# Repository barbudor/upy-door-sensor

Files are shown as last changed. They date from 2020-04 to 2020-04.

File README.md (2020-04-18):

# upy-door-sensor
Dead simple MQTT door-sensor based on ESP8266 (ESP01) with MicroPython

Using `umqttsimple.py` from [MicroPython-Lib](https://github.com/micropython/micropython-lib)
package (author: Paul Sokolovsky, license: MIT License).<br>
A big thanks to MicroPython authors and contributors.

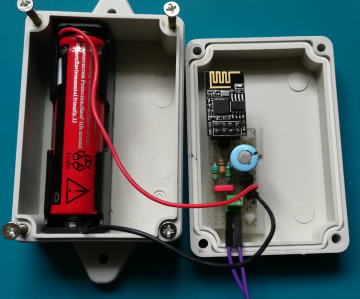
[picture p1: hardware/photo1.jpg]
photo should display here


# Principle of operation
The ESP8266 is maintained in permanent Deep Sleep state (do not connect GPIO16 to RESET).
A pulse is generated on RESET whenever the door opens and the switch closes, resulting in
waking up the ESP. Once awaken, the ESP8266 connects to the Wifi, the MQTT server and then
publish on a given topic before entering in Deep Sleep.

See hardware details in [`hardware/`](https://github.com/barbudor/upy-door-sensor/tree/master/hardware)
folder. Schematics avaible for both:
- [Circuit-Diagram.org](https://www.circuit-diagram.org/editor/)
- [Fritzing](http://fritzing.org/)

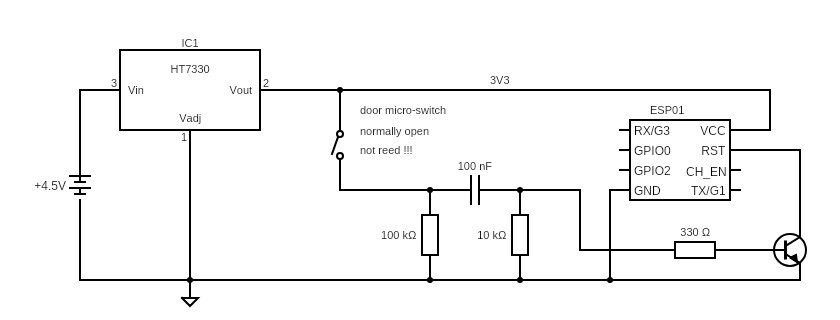
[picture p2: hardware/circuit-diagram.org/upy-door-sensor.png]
schematics should display here schematics

You must use a micro-switch which is open when the door is closed and closed when the door is open.
A reed switch is not suitable.

The MQTT message include a status for the door (always "open" as the sensor cannot detect
closing the door) and the VCC voltage. As soon as it drops below the regulator voltage, it means
that the battery is low and should be changed/charged.

# Configuration
No fancy web-server!
Configuration is performed by renaming `secrets_sample.py` as `secrets.py` and entering your
parameters. Should be self-explanatory.

Build and enjoy !

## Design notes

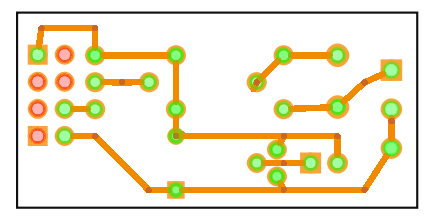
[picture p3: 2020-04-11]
hardware/fritzing/upy-door-sensor_pcb.png

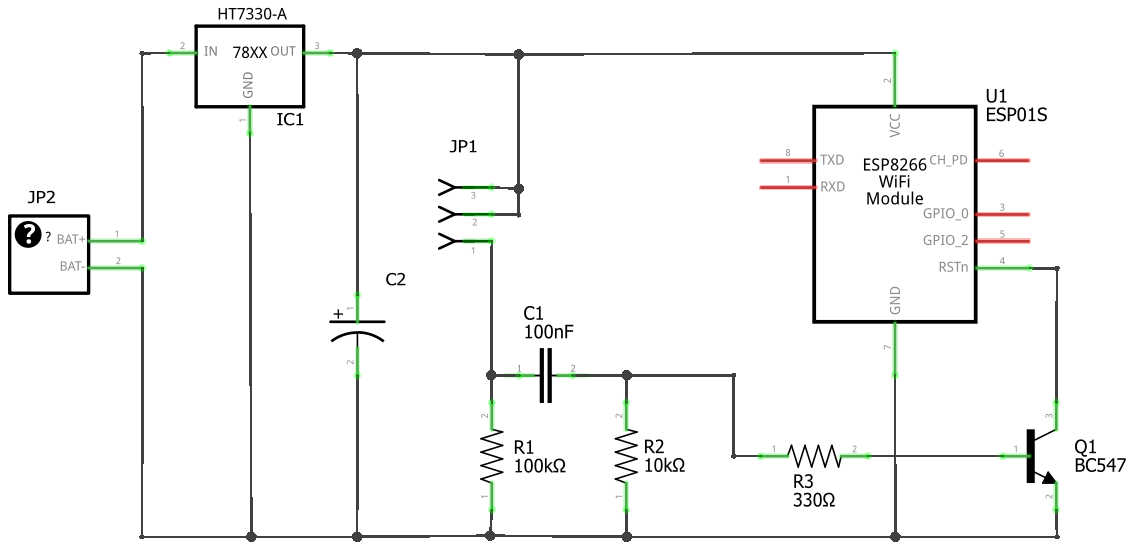
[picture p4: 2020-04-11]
hardware/fritzing/upy-door-sensor_schematics.png

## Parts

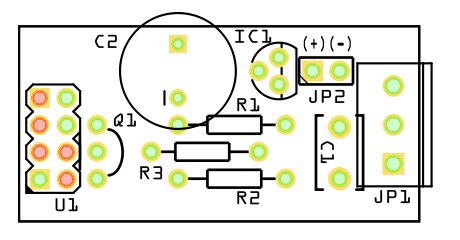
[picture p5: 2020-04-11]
hardware/fritzing/upy-door-sensor_parts-top.png

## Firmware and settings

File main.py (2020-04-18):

"""
    Quick and dirty MQTT door sensor
"""

import time
import network
import ubinascii
import machine
from umqttsimple import MQTTClient
import esp
import adcmode

try:
    import secrets
except:
    import secrets_sample as secrets

try:
    ### Create wifi network
    sta_if = network.WLAN(network.STA_IF)
    sta_if.active(True)
    print("wifi: connecting")
    sta_if.connect(secrets.SSID, secrets.PASSWD) # Connect to an AP
    try:
        sta_if.ifconfig((secrets.IPADDR, secrets.MASK, secrets.GW, secrets.DNS))
    except:
        print("using DHCP...")

    ### Setup ADC to measure VCC
    if not adcmode.set_adc_mode(adcmode.ADC_MODE_VCC):
        print("ADC mdode changed in flash - restart needed")
        machine.reset()
    vcc = machine.ADC(1).read()/1024.0

    while not sta_if.isconnected():
        time.sleep(0.5)

    print("wifi connected: ", sta_if.ifconfig())


    ### connect to MQTT
    CLIENT_ID = ubinascii.hexlify(machine.unique_id())
    client = MQTTClient(CLIENT_ID, secrets.MQTT_SVR, user=secrets.MQTT_USER, password=secrets.MQTT_PWD )
    client.connect()
    print("mqtt: connected")
    payload = secrets.MQTT_PAYLOAD.format(vcc)
    client.publish(secrets.MQTT_TOPIC, payload)
    print("mqtt: published %s: %s"%(secrets.MQTT_TOPIC, payload))
    client.disconnect()
    print("mqtt: disconnected")
except Exception as e:
    print( "FATAL: ", type(e) )
    print( "       ", repr(e) )

time.sleep(0.1) # without this, deepsleep doesn't work well
esp.deepsleep(0)

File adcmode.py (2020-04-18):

"""
    This module patches the flash to switch between ADC_VCC and ADC_A0 modes
    Courtesy of @ssendev and @eduvik on Github
    https://github.com/micropython/micropython/issues/2352
"""
import esp
from flashbdev import bdev
import machine

ADC_MODE_VCC = 255
ADC_MODE_ADC = 0

def set_adc_mode(mode):
    sector_size = bdev.SEC_SIZE
    flash_size = esp.flash_size() # device dependent
    init_sector = int(flash_size / sector_size - 4)
    data = bytearray(esp.flash_read(init_sector * sector_size, sector_size))
    if data[107] == mode:
        return True
    else:
        data[107] = mode  # re-write flash
        esp.flash_erase(init_sector)
        esp.flash_write(init_sector * sector_size, data)
        ## print("ADC mode changed in flash; restart to use it!")
    return False
